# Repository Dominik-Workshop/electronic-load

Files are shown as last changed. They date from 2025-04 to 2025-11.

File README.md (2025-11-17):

# DC Electronic Load

 

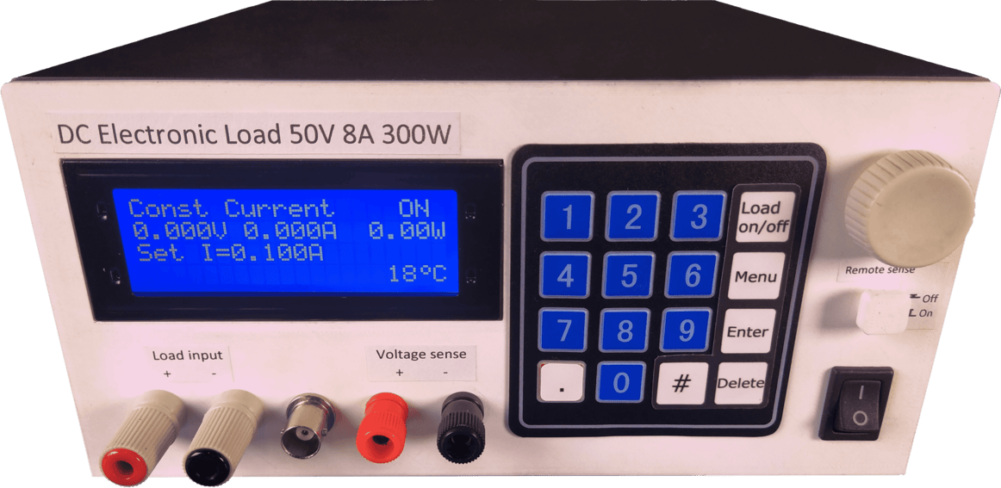
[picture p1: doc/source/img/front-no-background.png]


## Overview

Commercially available electronic loads often come with a hefty price tag, so I decided to build my own. 
This project was inspired by many electronic loads, with the primary inspiration being [Scullcom's Electronic DC Load](https://www.youtube.com/watch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).

### Key Features

- Supports up to **50 V** and **8 A** input
- Power dissipation: **200 W** continuous / **300 W** peak
- **Five operating modes**: constant current, power, resistance, step load, battery test
- **Remote voltage sensing**
- **User-friendly interface**: rotary encoder + numeric keypad
- **PC application** for real-time monitoring, control, and data logging
- **Fully open-source**: hardware, firmware, and software

### Learn More
<br>


## Project Status

✅ **Ready for construction!** <br>
The project is poised for construction and operational use. However, there might be some occasional updates to address minor bugs, introduce new features, or improve the overall user experience. Stay tuned for further developments!

## Electronics

The electronics architecture of the load is shown on the block diagram bellow:
Block diagram

This project contains 2 custom PCBs:
- [**Main board**](/pcb/pcb_main/): responsible for main funcionalities of the load

 

- [**Front board**](/pcb/pcb_front/): responsible for user input with the rotary encoder and switching the voltage measurement circuitry between the main and sense terminals

<p align="center">
   
</p>

## Mechanical

The case for this project is made with 1mm thick bent sheet metal, with a 3D printed front panel.

 
 

## PC App

To complement the electronic load, a dedicated desktop application is available. The application currently focuses on enhancing the **Battery Test Mode**, with potential support for other operating modes in future updates.

 

A pre-compiled, ready-to-use version for Windows is available for convenience in the project repository at: `desktop_app/release/windows-64bit/electronic_load_control_app.exe`

## Accuracy Measurements

<details>
<summary>Click to learn more</summary>

The precision of the electronic load's current and voltage measurements, as well as its set current accuracy, were tested against the `Sanwa PC7000` multimeter. The following tables present the results of these measurements.

**Set And Measured Current**
| Set Value [A] | Load Measurement [A] | Multimeter Measurement [A]  |
|:---|:---|:---|
| 0.1 | 0.104 | 0.1032 ± 0.0029 |
| 0.2 | 0.203 | 0.2024 ± 0.0037 |
| 0.3 | 0.300 | 0.3000 ± 0.0044 |
| 0.4 | 0.406 | 0.4051 ± 0.0053 |
| 0.5 | 0.500 | 0.4997 ± 0.0060 |
| 0.6 | 0.602 | 0.6020 ± 0.0069 |
| 0.7 | 0.702 | 0.7020 ± 0.0077 |
| 0.8 | 0.800 | 0.8000 ± 0.0084 |
| 0.9 | 0.904 | 0.9038 ± 0.0093 |
| 1.0 | 1.007 | 1.0065 ± 0.0101 |
| 2.0 | 2.007 | 2.0070 ± 0.0181 |
| 3.0 | 3.006 | 3.0057 ± 0.0261 |
| 4.0 | 4.003 | 4.0022 ± 0.0341 |
| 5.0 | 5.002 | 5.0007 ± 0.0421 |
| 6.0 | 6.001 | 5.996 ± 0.068 |
| 7.0 | 6.998 | 6.997 ± 0.076 |
| 8.0 | 7.998 | 7.990 ± 0.084 |

**Voltage**
| Load Measurement [V] | Multimeter Measurement [V] |
|:---|:---|
| 1.002 | 1.0022 ± 0.0006 |
| 2.002 | 2.0029 ± 0.0009 |
| 3.004 | 3.0043 ± 0.0012 |
| 4.004 | 4.0039 ± 0.0015 |
| 5.006 | 5.0058 ± 0.0018 |
| 8.004 | 8.004 ± 0.006 |
| 10.01 | 10.007 ± 0.007 |
| 12.01 | 12.008 ± 0.007 |
| 14.01 | 14.010 ± 0.008 |
| 16.01 | 16.004 ± 0.009 |
| 18.01 | 18.007 ± 0.010 |
| 20.01 | 20.008 ± 0.011 |
| 25.01 | 25.011 ± 0.013 |
| 30.02 | 30.016 ± 0.015 |
| 35.02 | 35.019 ± 0.017 |
| 40.02 | 40.019 ± 0.019 |
| 45.02 | 45.023 ± 0.021 |
| 50.01 | 50.012 ± 0.023 |

**Conclusion**

✅The current values measured by the electronic load did not deviate from the set value by more than **7 mA**. All measurements taken by the electronic load are within the range of values measured by the multimeter, considering the multimeter's measurement error.
</details>

## Used Tools

- [Autodesk EAGLE](https://www.autodesk.com/products/eagle/) - Schematic and PCB design
- [Autodesk Fusion 360](https://www.autodesk.com/products/fusion-360/) - 3D modeling
- [PlatformIO](https://platformio.org/) + [Visual Studio Code](https://code.visualstudio.com/) - Firmware development
- [Qt](https://www.qt.io/) (C++) - Desktop application for monitoring and control

## Special Thanks

Special thanks to [**Eryk Możdzeń**](https://github.com/Eryk-Mozdzen), who helped solving a software problem with a memory leak.

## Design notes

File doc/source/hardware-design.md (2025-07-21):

## 🔩 Mechanical

### Panel Layouts
The diagrams below show the layout of all external controls and connectors:

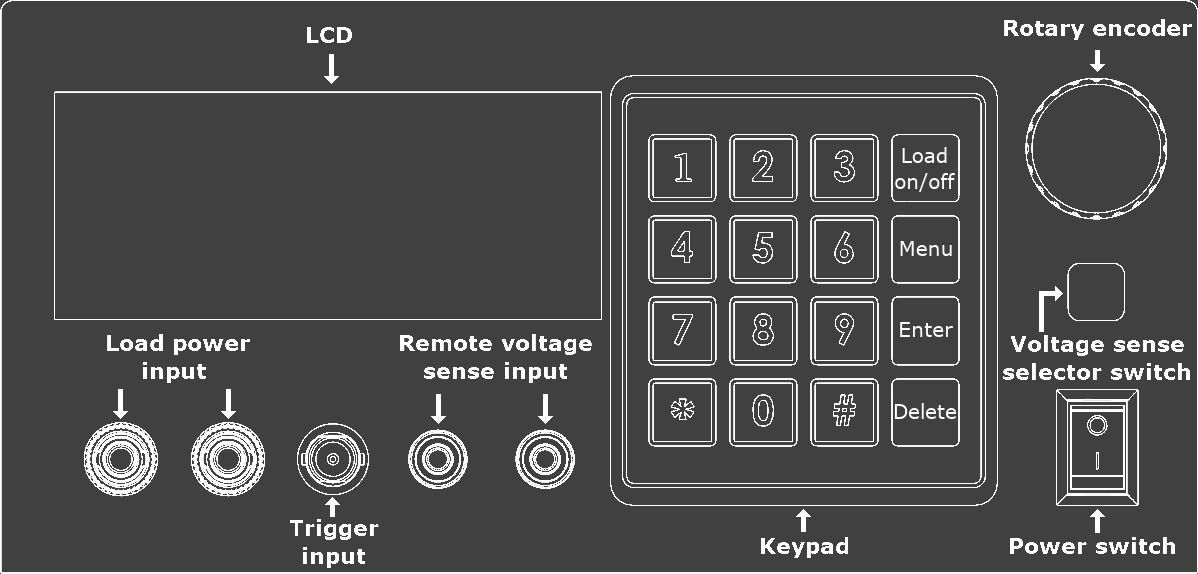
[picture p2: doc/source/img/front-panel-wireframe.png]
Annotated Front Panel Wireframe

/// caption
Annotated Front Panel Wireframe
///

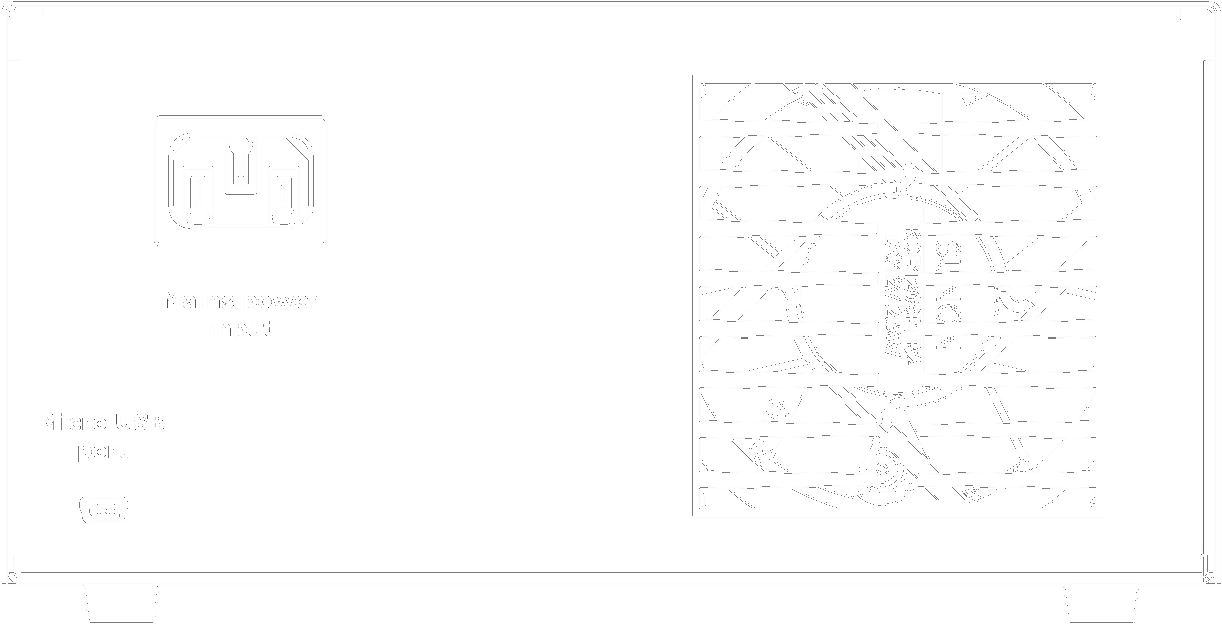
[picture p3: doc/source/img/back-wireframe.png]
Annotated Back Panel Wireframe

/// caption
Annotated Back Panel Wireframe
///

### Enclosure and Cooling
The enclosure is a hybrid construction designed for durability and ease of assembly. The main chassis is formed from 1mm thick sheet steel, which was CNC laser-cut and then bent into shape. This provides a sturdy frame for all internal components.

The front panel is a custom 3D-printed part, allowing for precise mounting of the display, keypad, switches, and connectors.

Heat from the power MOSFETs is dissipated by a large, tunnel-style aluminum heatsink, which is actively cooled by a temperature-controlled fan. The complete internal assembly can be seen in the image below.

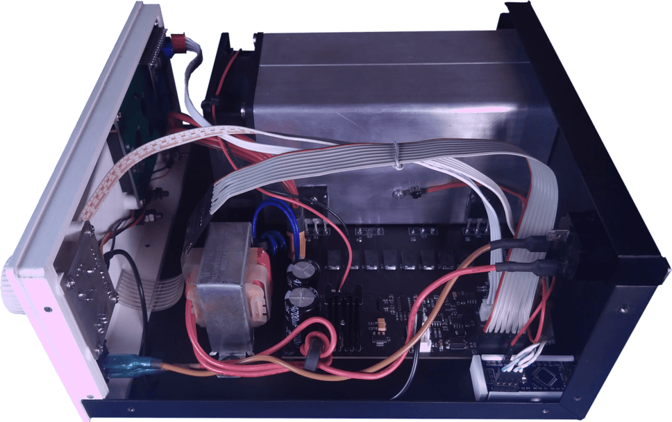
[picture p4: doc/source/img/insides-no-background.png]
Internal view of the electronic load

/// caption
Internal view of the electronic load
///

## ⚡ Electronics

### Input Specifications

<div class="grid cards" markdown>

-   __Load power input [*(Front panel)*](#fig:front-panel-wireframe)__

    ---
    - **Max voltage:** 50V DC
    - **Max current:** 8A
    - **Max dissipated power:** 300W (10 min)¹ / 200W (cont.)²

-   __Remote voltage sense input [*(Front panel)*](#fig:front-panel-wireframe)__

    ---
    - **Max voltage:** 50V DC

-   __Mains power input [*(Back panel)*](#fig:back-panel-wireframe)__

    ---
    - **Voltage:** 230V AC
    - **Max power consumption:** 10W

-   __Trigger input [*(Front panell)*](#fig:front-panel-wireframe)__

    ---
    - **Max voltage:** 5V DC

</div>

¹ *Assumes ambient temperature of 25°C.* <br>
² *Assumes an initial heatsink temperature of 25°C.*

### Architecture Overview

Electronics block diagram
/// caption
Electronics block diagram
///

The system's architecture is orchestrated by an `ATmega328P` microcontroller. It interfaces with several key components via I2C, including a 12-bit `MCP4725` DAC to set the load current, a 16-bit `ADS1115` ADC to measure voltage and current, and an `MCP79410` RTC for time-critical operations like battery capacity testing.

The core of the load is the Constant Current Sink, controlled by the DAC and built around `AD8630` operational amplifier and `IRFP250` power MOSFETs. The ADC measures the current flowing through this sink and the voltage at the input terminals. A switch, controlled from the front panel, allows the voltage measurement to be taken either from the main power terminals or from the remote sense terminals via a differential amplifier built on an `OPA277` op-amp. User interaction is managed through a rotary encoder, keypad, and a 4x20 LCD display, while PC communication is handled by a dedicated USB-to-UART converter board.

A transformer provides AC power, which is converted by the internal power supply section into three DC rails: **+12V** (for the cooling fan), **+5V** (for logic and analog circuits), and **-5V** (for the symmetrical supply of the differential amplifier).

### PCBs
The system's electronics are distributed across three distinct PCBs. The functional blocks residing on each board are color-coded for clarity in the [*Electronics block diagram*](#fig:block-diagram) shown above.

- **Main board**: This two-layer PCB performs all core control, measurement, and power handling functions of the electronic load.

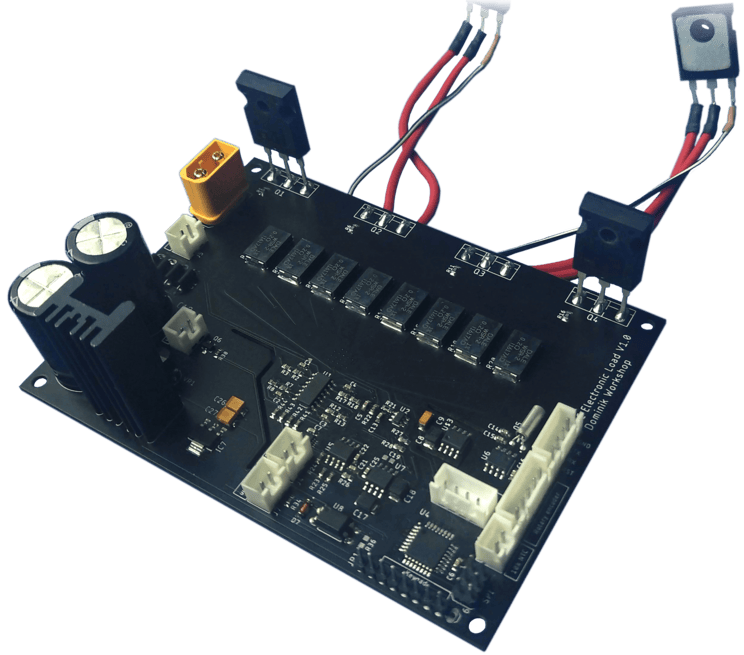
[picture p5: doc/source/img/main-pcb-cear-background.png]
Main PCB photo


- **Front board**: This single-layer PCB functions as the user interface board, handling manual controls and routing for the voltage measurement signals.

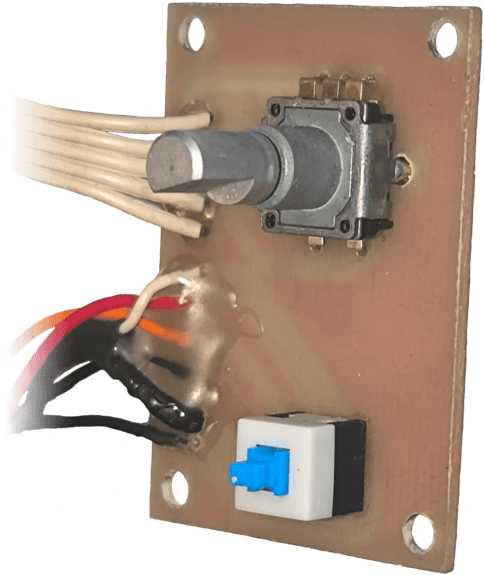
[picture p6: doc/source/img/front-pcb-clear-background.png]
Front PCB photo


- <span id="fig:converter-board"></span>**Converter board**: Acts as a dedicated communication bridge for PC control, data acquisition and allows for programming of the main microcontroller. This was implemented cost-effectively by using a modified Arduino Nano board with its original microcontroller desoldered, leaving only the `CH340` USB-to-serial IC functional.

=== "Angle view"

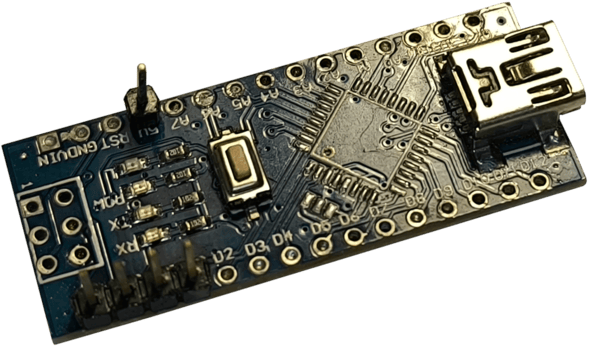
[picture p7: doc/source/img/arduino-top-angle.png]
Arduino angle view
    

=== "Top view"

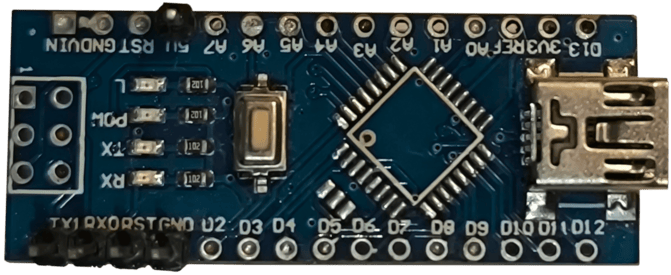
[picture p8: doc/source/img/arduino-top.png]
Arduino top view
    

=== "Bottom view"

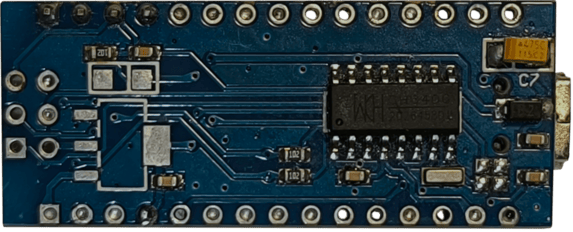
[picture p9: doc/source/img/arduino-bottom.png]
Arduino bottom view


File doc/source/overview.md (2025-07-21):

# DC Electronic Load

## 🎥 Introduction

Watch a full project overview on [YouTube](https://youtu.be/NScaRQj53l0).

This open-source programmable **DC electronic load** is designed to test power supplies, batteries, and other DC sources. It simulates a variety of load conditions to evaluate performance and reliability.

The design was inspired by several community projects, especially [Scullcom’s Electronic DC Load](https://www.youtube.com/watch?v=9fsf1CgnTRk).

## ⚙️ Key Features

- Supports up to **50 V** and **8 A** input
- Power dissipation: **200 W** continuous / **300 W** peak
- **Five operating modes**: constant current, power, resistance, step load, battery test
- **Remote voltage sensing**
- **User-friendly interface**: rotary encoder + numeric keypad
- **PC application** for real-time monitoring, control, and data logging
- **Fully open-source**: hardware, firmware, and software

## 🛠️ Tools Used

<table style="width: 100%; border-collapse: collapse;">
  <thead>
    <tr style="border-bottom: 2px solid #ccc;">
      <th style="text-align: left; padding: 8px;">Tool</th>
      <th style="text-align: left; padding: 8px;">Usage</th>
    </tr>
  </thead>
  <tbody>
    <tr>
      <td style="padding: 8px;"><strong>Autodesk Eagle</strong></td>
      <td style="padding: 8px;">Schematic and PCB design</td>
    </tr>
    <tr>
      <td style="padding: 8px;"><strong>Fusion 360</strong></td>
      <td style="padding: 8px;">3D modeling for the enclosure and front panel</td>
    </tr>
    <tr>
      <td style="padding: 8px;"><strong>PlatformIO + VS Code</strong></td>
      <td style="padding: 8px;">Firmware development and microcontroller programming</td>
    </tr>
    <tr>
      <td style="padding: 8px;"><strong>Qt (C++ with Qt)</strong></td>
      <td style="padding: 8px;">Desktop application for monitoring and control</td>
    </tr>
  </tbody>
</table>

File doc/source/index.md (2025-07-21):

# DIY Electronic Load Documentation

Welcome to the official documentation for the **DIY Electronic Load** project. Here you'll find the key information needed to understand the design, and to build and use your own device.

Hero Image

---

## Table of Contents

<div class="grid cards" markdown>

-   __Project Overview__

    ---
    Learn about the project's goals, key features, and the tools used in its creation.

    [:octicons-arrow-right-24: Read the Overview](overview.md)

-   __Hardware Design__

    ---
    A deep dive into the schematics, PCB layouts, and mechanical design of the enclosure.

    [:octicons-arrow-right-24: Explore the Hardware](hardware-design.md)

-   __Software & Firmware__

    ---
    Instructions for programming the microcontroller, calibrating the device, and using the PC application.

    [:octicons-arrow-right-24: View Software & Firmware Docs](software.md)

-   __Testing & Performance__

    ---
    See the results of functional tests and performance measurements for the completed device.

    [:octicons-arrow-right-24: See Performance Data](testing-performance.md)

</div>

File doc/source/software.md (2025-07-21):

## 💾 Microcontroller Firmware

The heart of the electronic load is the custom firmware running on its ATmega328P microcontroller.

The firmware is written in C++ and was developed using **Visual Studio Code** with the **PlatformIO** extension. This setup is recommended as it simplifies managing the project's libraries and build configurations. While it's possible to adapt the project for other environments like the Arduino IDE, using PlatformIO is the most straightforward path.

### Programming Options

There are two methods to upload the firmware to the microcontroller:

- **USB**

    This is the simplest method and uses the [Micro USB port](hardware-design.md#fig:back-panel-wireframe) on the back panel. This connection utilizes the onboard [converter board](hardware-design.md#fig:converter-board) to communicate with the microcontroller's TX/RX pins.

    !!! warning
        This method will only work if the ATmega328P microcontroller already has an Arduino-compatible bootloader installed.

- **ICSP Programmer**

    This method programs the microcontroller directly. It is the primary way to:

    - Upload firmware to a microcontroller that does not have a bootloader.
    - Burn a bootloader onto the microcontroller, which then enables the simpler USB programming method.

    This method offers two key advantages over using a bootloader. First, it frees up flash memory, which can be helpful given the memory constraints of the ATmega328P. Second, it reduces the device's startup time, as the firmware runs immediately on power-up instead of waiting for the bootloader's timeout period.

    The [main board](hardware-design.md#pcbs) includes a standard 6-pin ICSP (In-Circuit Serial Programming) header for connecting an external programmer, such as a **USBasp**.

    !!! note "Uploading with ICSP erases the bootloader"
        When you upload firmware directly using an ICSP programmer, it overwrites the entire flash memory of the microcontroller, including the bootloader. If you want to use the USB method again later, you will need to re-burn the bootloader using the ICSP programmer.

    To use this method with PlatformIO, you must add the following configuration to your `platformio.ini` file:

    ```ini
    upload_protocol = custom
    upload_port = usb
    upload_flags = 
        -C
        ${platformio.packages_dir}/tool-avrdude/avrdude.conf
        -p
        $BOARD_MCU
        -P
        $UPLOAD_PORT
        -c
        usbasp
    upload_command = avrdude $UPLOAD_FLAGS -U flash:w:$SOURCE:i
    ```

### Calibration Procedure

!!! tip "Video Guide Available"
    A complete video guide is available on YouTube. It provides a full walkthrough of the calibration procedure, including the required hardware setup, modifying the firmware, and using the on-screen menu.

    [Watch the calibration guide here](https://www.youtube.com/watch?v=jx0t7Ovq4uw&t=114s)

To ensure both measurement (ADC) and setpoint (DAC) accuracy, a calibration routine is included in the firmware.
This procedure only needs to be performed once, as the resulting calibration values are stored permanently in the microcontroller's EEPROM.

!!! info "Memory Limitation"
    Due to the limited flash memory on the ATmega328P, the calibration function is disabled by default to make space for all the primary operating modes. You must temporarily modify the source code to access it.

Follow these steps to enable the calibration mode:

1.  **Enable the Calibration Menu:** In the `main.cpp` source file, find and uncomment the `case '6'` block for the calibration function:

    ```cpp
    case '6':
        calibration(lcd, userInput, keypad, encoder, measurements, controls);
        displayMenu(lcd);
        break;
    ```

2.  **Disable Another Mode:** To free up enough memory, you must temporarily comment out another mode. For example, you can disable the **Transient Response Mode**:

    ```cpp
    
    // case '4':
    //    transientResponseMode(lcd, userInput, keypad, encoder, measurements, controls, transient);
    //    displayMenu(lcd);
    //    break;
    ```

3.  **Upload and Calibrate:** Compile and upload the modified firmware. The calibration menu will now be accessible by pressing `6` in the main menu of the load.

!!! danger "Important"
    After you have completed the calibration, you **must** revert these changes (re-comment the calibration block and un-comment the mode you disabled) and re-upload the firmware to restore full functionality.

## 🖥️ PC Application

To complement the electronic load, a dedicated desktop application is available. The application currently focuses on enhancing the **Battery Test Mode**, with potential support for other operating modes in future updates.

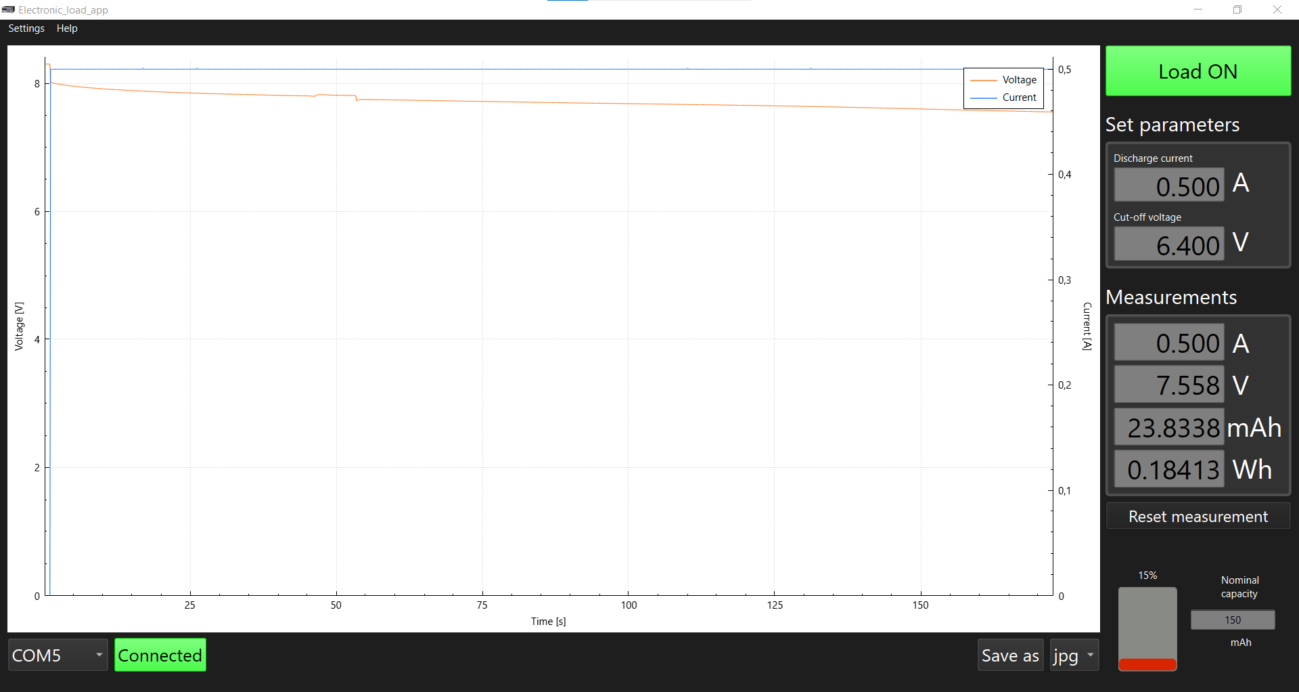
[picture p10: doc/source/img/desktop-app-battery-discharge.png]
PC Application Interface

/// caption
The PC application interface during a battery discharge test.
///

### Key Features

- **Remote Control:** Set the battery discharge current and the cut-off voltage directly from the application.
- **Real-Time Visualization:** View live plots of the battery's voltage and current throughout the discharge test.
- **Data Export:** Save the recorded discharge graph as a JPG image or export the raw measurement data as a CSV file for further analysis in other software.
- **Multi-Language Support:** The user interface is available in English, Polish, and German.

### Technical Details

The application communicates with the electronic load via a serial connection through the [Micro USB port](hardware-design.md#fig:back-panel-wireframe). It was developed in C++ using the Qt framework, which allows it to be cross-platform.

### Availability

!!! tip "Windows Users"
    A pre-compiled, ready-to-use version for Windows is available for convenience in the project repository at:
    `desktop_app/release/windows-64bit/electronic_load_control_app.exe`

!!! info "Linux and Other OS Users"
    Since the application is built with the cross-platform Qt framework, it can be compiled for other operating systems like Linux. The full source code is available in the repository for users who wish to build it themselves. Pre-compiled binaries for Linux may be added in the future.

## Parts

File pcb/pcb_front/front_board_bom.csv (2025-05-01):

Id | Designator | Footprint | Quantity | Designation | Supplier and ref
1 | SW1 | ALPS_EC12E_SW_373 | 1 | EC12E_SW
2 | JP1 | 1X05_90_325 | 1
3 | R1,R2 | R0603_334 | 2 | 4k7
4 | R3 | R0603_334 | 1 | 12k
5 | S1 | TL4XPO_380 | 1 | TL2285EE
6 | JP4,JP3,JP2 | 1X02_90_325 | 3
7 | C1,C2,C3 | C0603_334 | 3 | 100n

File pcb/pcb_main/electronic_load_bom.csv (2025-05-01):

Id | Designator | Footprint | Quantity | Designation | Supplier and ref
1 | Q1,Q2,Q3,Q4 | TO-247AD-V_400 | 4 | IRFP250
2 | U1 | ANALOG_DEVICES_AD8630ARZ-REEL7_0 | 1 | ANALOG_DEVICES_AD8630ARZ-REEL7ANALOG_DEVICES_AD8630ARZ-REEL7_0_0
3 | R1,R6,R11,R16,R31 | R0805_334 | 5 | 1k
4 | R2,R7,R12,R17,R30,R34,R41,R42,R43,R44 | R0603_334 | 10 | 1k
5 | C1,C5,C2,C3,C4 | C0603_334 | 5 | 1n
6 | U2 | SOT95P270X145-6N | 1 | MCP4725A0T-E/CH
7 | R21,R3,R8,R13,R18,R24,R26,R35,R36,R29 | R0603_334 | 10 | 10k
8 | R22 | R0603_334 | 1 | 560R
9 | U3 | MSOP10 | 1 | ADS1115
10 | U4 | QFP80P900X900X120-32N | 1 | ATMEGA328P-AU
11 | C6,C7,C13,C16,C21,C22,C25 | C0603_334 | 7 | 100n
12 | J1 | AMASS_XT60-M | 1 | XT60-M
13 | R4,R5,R9,R10,R14,R15,R19,R20 | R4527_334 | 8 | 0R2
14 | R23,R25 | R0603_334 | 2 | 1M
15 | C11,C12 | E7,5-16_334 | 2 | 4700u
16 | R27,R28 | R0603_334 | 2 | 4k7
17 | U5 | SOIC-08_150MIL | 1 | OPA277
18 | U6 | SOIC127P600X175-8N | 1 | MCP79410-I/SN
19 | Q5 | TC26H_204 | 1 | 32768Hz
20 | C14,C15 | C0603_334 | 2 | 6-9p
21 | U7 | SOIC8 | 1 | ICL7660CPAZSOIC
22 | C17,C18,C8 | CT3528_334 | 3 | 10u
23 | C19 | C0603_334 | 1 | omit
24 | SPI0 | MA03-2_162 | 1
25 | J4,J2,J5,J6,J7 | JST_B2B-XH-A(LF)(SN) | 5 | B2B-XH
26 | Q6 | SOT23 | 1 | IRLML6244
27 | D5 | DO-214AC | 1 | BYG22B
28 | J3,JP2 | JST_B4B-XH-A(LF)(SN) | 2 | B4B-XH
29 | C23 | C0603K_334 | 1 | 100n
30 | D1,D2,D3,D4 | DO41-7.6_210 | 4 | 1N5819-B
31 | Q7 | TO220V | 1 | BD911
32 | VR1 | TO92-CLP | 1 | TL431
33 | R32 | R0603_334 | 1 | 68k
34 | R33 | R0603_334 | 1 | 18k
35 | IC7 | SOT223 | 1 | LM1117-5.0
36 | C26,C27 | B_3528-21W_334 | 2 | 10u
37 | U$1 | TO220_HEATSINK | 1 | TO220_HEATSINK
38 | U8 | SOT254P975X400-4N | 1 | PC817X2NIP0F
39 | Q8,Q9,Q10,Q11 | SOT23 | 4 | S9015
40 | R37,R38,R39,R40 | R0603_334 | 4 | 100k
41 | D7 | DIOMELF3515N | 1 | LL4148
42 | C28,C29 | C0603_334 | 2 | 22p
43 | U$3 | SOIC8 | 1 | LM4140
44 | C9 | CT3216_334 | 1 | 1u
45 | J8 | JST_B5B-XH-A(LF)(SN) | 1 | B5B-XH
46 | JP1 | 1X09_325 | 1
47 | U$2 | CRYSTAL_3,4X2,7 | 1 | 16MHz
48 | C10 | C0603_334 | 1 | 1u

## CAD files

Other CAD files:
3d_models/blends/TO-247_vertical.blend

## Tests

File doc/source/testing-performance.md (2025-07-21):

## Calibration & Accuracy

The precision of the electronic load's current and voltage measurements, as well as its set current accuracy, were tested against the `Sanwa PC7000` multimeter. The following tables present the results of these measurements.

### Accuracy of set and measured current values

| Set Value [A] | Load Measurement [A] | Multimeter Measurement [A]  |
|:---|:---|:---|
| 0.1 | 0.104 | 0.1032 ± 0.0029 |
| 0.2 | 0.203 | 0.2024 ± 0.0037 |
| 0.3 | 0.300 | 0.3000 ± 0.0044 |
| 0.4 | 0.406 | 0.4051 ± 0.0053 |
| 0.5 | 0.500 | 0.4997 ± 0.0060 |
| 0.6 | 0.602 | 0.6020 ± 0.0069 |
| 0.7 | 0.702 | 0.7020 ± 0.0077 |
| 0.8 | 0.800 | 0.8000 ± 0.0084 |
| 0.9 | 0.904 | 0.9038 ± 0.0093 |
| 1.0 | 1.007 | 1.0065 ± 0.0101 |
| 2.0 | 2.007 | 2.0070 ± 0.0181 |
| 3.0 | 3.006 | 3.0057 ± 0.0261 |
| 4.0 | 4.003 | 4.0022 ± 0.0341 |
| 5.0 | 5.002 | 5.0007 ± 0.0421 |
| 6.0 | 6.001 | 5.996 ± 0.068 |
| 7.0 | 6.998 | 6.997 ± 0.076 |
| 8.0 | 7.998 | 7.990 ± 0.084 |

### Accuracy of voltage measurements

| Load Measurement [V] | Multimeter Measurement [V] |
|:---|:---|
| 1.002 | 1.0022 ± 0.0006 |
| 2.002 | 2.0029 ± 0.0009 |
| 3.004 | 3.0043 ± 0.0012 |
| 4.004 | 4.0039 ± 0.0015 |
| 5.006 | 5.0058 ± 0.0018 |
| 8.004 | 8.004 ± 0.006 |
| 10.01 | 10.007 ± 0.007 |
| 12.01 | 12.008 ± 0.007 |
| 14.01 | 14.010 ± 0.008 |
| 16.01 | 16.004 ± 0.009 |
| 18.01 | 18.007 ± 0.010 |
| 20.01 | 20.008 ± 0.011 |
| 25.01 | 25.011 ± 0.013 |
| 30.02 | 30.016 ± 0.015 |
| 35.02 | 35.019 ± 0.017 |
| 40.02 | 40.019 ± 0.019 |
| 45.02 | 45.023 ± 0.021 |
| 50.01 | 50.012 ± 0.023 |

**Conclusion** ✅

The current values measured by the electronic load did not deviate from the set value by more than **7 mA**. All measurements taken by the electronic load are within the range of values measured by the multimeter, considering the multimeter's measurement error.

## Thermal Performance

At full load (300 W for short periods), the device maintained safe thermal conditions due to a heatsink and active fan cooling. Continuous operation at 200 W is sustainable.

## Step Response

Step changes in load (1–3 A, 3–5 A, 6–8 A) showed fast transitions with no overshoot or oscillation. This confirms stable control loop performance.

=== "Transients 24V"
    
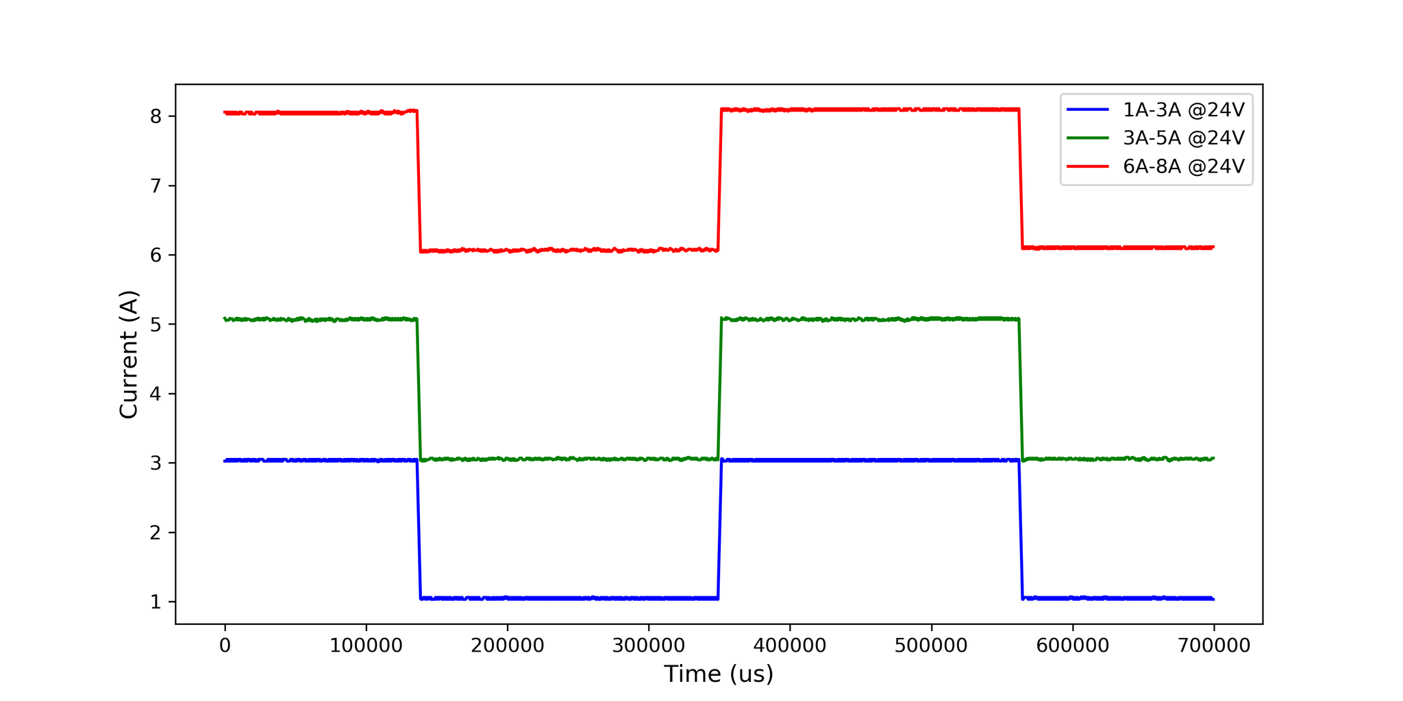
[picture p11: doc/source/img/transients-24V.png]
Transient 20V
    

=== "Transients 5V"

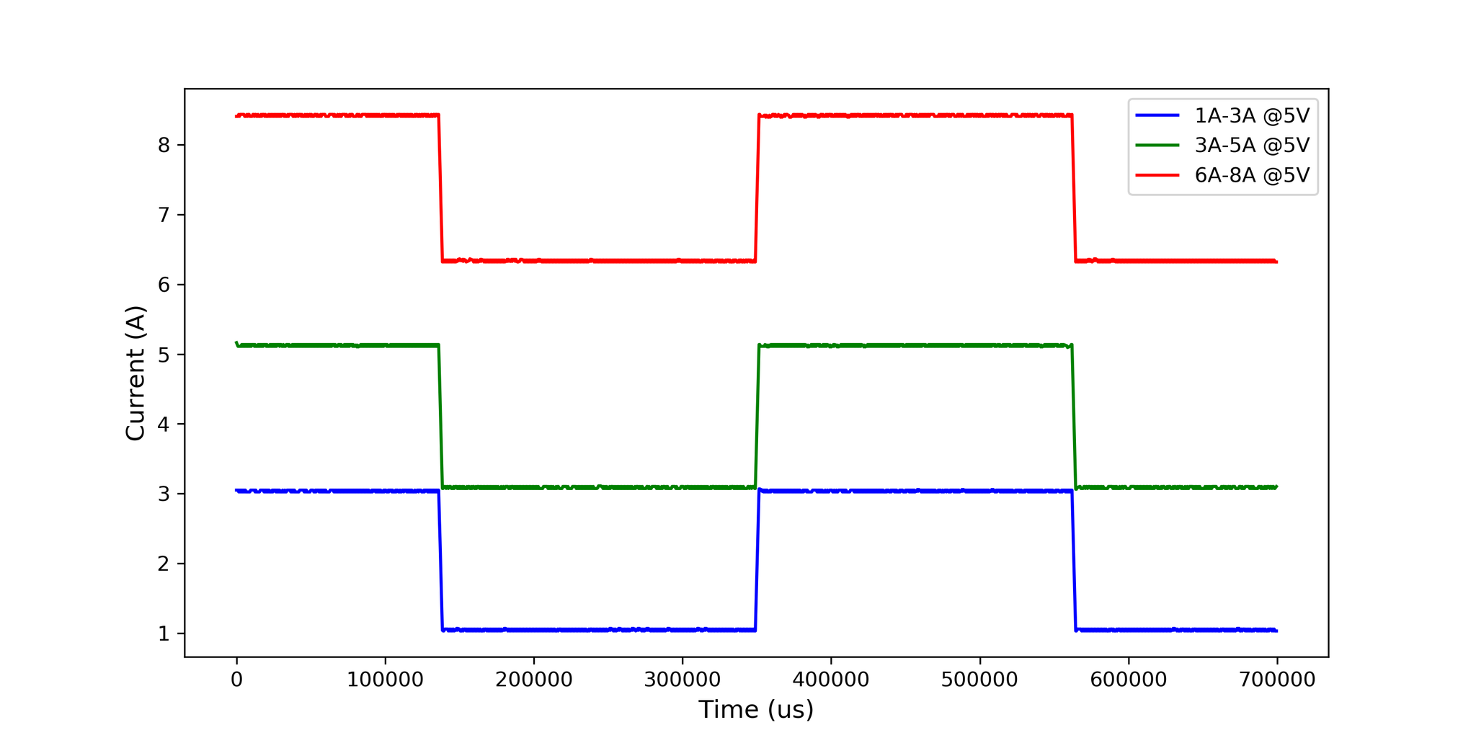
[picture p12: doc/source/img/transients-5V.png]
Transient 5V
    

## Battery Testing

The battery test mode successfully measured capacity by monitoring discharge current and cutoff voltage. Data was logged and visualized in the PC application.

## Tools Used for Testing

- Sanwa PC7000 Multimeter
- Rigol MSO2102A Oscilloscope
- AXIOMET AX-3005PQ Power Supplies

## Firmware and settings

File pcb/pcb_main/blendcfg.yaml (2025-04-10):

default:
  SETTINGS:
    PRJ_EXTENSION: .sch     # file extension used to derive name for generated blend file e.g. example.kicad_pro -> example.blend, type "" if unspecified
    FAB_DIR: fab                  # default directory name containing input fabrication (gerber) files
    DPI: 900                      # quality of bitmaps exported from Gerbers, influences board model creation time
    DEFAULT_BRD_THICKNESS: 1.6    # used when stackup effect is turned off
    SILKSCREEN: White             # options: White (default), Black
    SOLDERMASK: Black             # options: Black (default), White, Green, Blue, Red
                                  # for custom color, type pair of hex values: AABBCC, DDEEFF (colors for areas with and without copper beneath)
    USE_INKSCAPE: true            # use when board has overlapping holes footprints, sometimes fixes mesh generation

    BOM_DIR: doc
    MODEL_LIBRARY_PATHS:            # default paths to model library folders, can be overridden by MODEL_LIBRARY_PATHS
      - $HOME/.local/share/antmicro-blender-models/
      - $HOME/.local/share/antmicro-hardware-components/
      - $HOME/antmicro/hardware-components/
      - $HOME/projects/electronic-load/3d_models
    APPLY_TRANSFORMS: true
    RENDER_DIR: renders
    ANIMATION_DIR: animations
    IMAGE_FORMAT:                     # list of formats for static image outputs (all supported by Blender)
      - PNG
    VIDEO_FORMAT:                     # list of formats for static image outputs (GIF, AVI, WEBM, MP4, MPEG)
      - WEBM
    THUMBNAILS: false
    KEEP_FRAMES: false
    SAVE_SCENE: false
  GERBER_FILENAMES:
    EDGE_CUTS: '*-Edge_Cuts.gbr'
    PTH: '*-PTH-drl.gbr'
    NPTH: '*-NPTH-drl.gbr'
    IN: '*-In*.gbr'
    FRONT_SILK: '*-F_Silkscreen.gbr'
    BACK_SILK: '*-B_Silkscreen.gbr'
    FRONT_MASK: '*-F_Mask.gbr'
    BACK_MASK: '*-B_Mask.gbr'
    FRONT_CU: '*-F_Cu.gbr'
    BACK_CU: '*-B_Cu.gbr'
    FRONT_FAB: '*-F_Fab.gbr'
    BACK_FAB: '*-B_Fab.gbr'
    FRONT_PASTE: '*-F_Paste.gbr'
    BACK_PASTE: '*-B_Paste.gbr'

  EFFECTS:
    STACKUP: false                 # if True, requires stackup.json output
    SOLDER: true                  # generates solder on pads of mounted components, requires solder paste gerbers

    SHOW_MECHANICAL: false
    SHOW_MARKINGS: true
  STAGES:
    - CLEARSCENE:
    - GERBCONVERT:
    - BOARD:
    - VERSIONSTAMPER:
  RENDERER:
    SAMPLES: 32                       # Cycles renderer samples, influence quality of final render and rendering times
    FPS: 25                           # animation frames per second value 
    IMAGE_WIDTH: 4096                 # rendered image width
    IMAGE_HEIGHT: 4096                # rendered image height
    VIDEO_WIDTH: 740                  # sequenced animation width
    VIDEO_HEIGHT: 740                 # sequenced animation height
    THUMBNAIL_WIDTH: 320              # thumbnail image copy width
    THUMBNAIL_HEIGHT: 320             # thumbnail image copy height

  SCENE:
    LIGHTS_COLOR: FFFFFF              # area lights color (accepts hex values, for example AABBCC) 
    LIGHTS_INTENSITY: 1.0             # area lights intensity float multiplier, set to 0.0 to disable area lights
    HDRI_INTENSITY: 0.5               # HDRI background intensity float multiplier, set to 0.0 to disable HDRI 
    DEPTH_OF_FIELD: true              # enable depth of field for all cameras
    FOCAL_RATIO: auto                 # cameras' focal ratio for depth of field effect, (accepts fractions like f/4, 1/4 or floats, type "auto" for calculated value)
    ZOOM_OUT: 1.05                    # cameras' zoom applied when framing rendered object (zoom_out < 1.0 - zoom in, zoom_out > 1.0 - zoom out)
    LED_ON: true                      # enable light emitting shaders on model
    ADJUST_POS: true                  # enable automatic position adjustments based on model type before rendering
    ORTHO_CAM: false                  # enables orthographic-like camera mode for all cameras
    RENDERED_OBJECT:                  # specify part of the model to be used as render object, uses "Object/<name>" or "Collection/<name>" syntax

  BACKGROUNDS:                        # background selection
    LIST:                             # name of .blend file from src/pcbooth/templates/backgrounds directory or "transparent"                                         
      - paper_black

  CAMERAS:                            # camera selection
    TOP: true
    ISO: true
    FRONT: true
    LEFT: true
    RIGHT: true
    PHOTO1: true
    PHOTO2: true
    CUSTOM: false

  POSITIONS:                          # model position selection
    TOP: true
    BOTTOM: false
    REAR: false

  OUTPUTS:                            # rendering jobs list
    - STATIC:
demo:
  CAMERAS:
    TOP: true
    PHOTO1: true
  POSITIONS:
    TOP: true
  OUTPUTS:
    - STATIC:
    - CAMERATRANSITION:

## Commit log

2025-03-29 Reverse calibration order: first offset then multiplier
2025-03-29 Add voltage and current accuracy measurements results to README
    Add voltage and current accuracy measurements results to README
2025-03-29 [#6] Add gerber files named in KiCad naming scheme
    [electronic-load-B_Cu.gbr, electronic-load-B_Mask.gbr, electronic-load-B_Paste.gbr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]
2025-03-29 [#6] Add positional file and blendcfg.yaml
    [electronic-load-pos.csv]
2025-03-29 [#6] Generate PCB blend model
2025-03-29 [#6] Addjust component position in pos.csv file, move it to /fab
    [electronic-load-pos.csv]
2025-03-29 [#6] Match component blend models
    [electronic-load-pos.csv]
2025-04-10 [#6] Add TO-247
    [TO-247_vertical.blend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]
2025-05-01 Add BOM files
    [electronic_load_bom.csv, front_board_bom.csv]
2025-07-24 Update main PCB render in README
